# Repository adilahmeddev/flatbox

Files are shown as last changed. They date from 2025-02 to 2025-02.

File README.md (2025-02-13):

# Flatbox: Low profile hitbox-layout fightstick

This repository contains 3D-printable models, PCB design files and code needed to make an arcade controller that looks like this:

Assembled Flatbox

There are seven major versions of the Flatbox. They all use Kailh low profile (choc v1) mechanical keyboard switches. The table below lists their main features. See the README for each version for details on how to make them.

version | case dimensions (mm) | compatibility | add-on board | onboard chip | SMT assembly required | firmware
------- | --------------- | ------------- | ------------ | ------------ | --------------------- | --------
[rev1.1](hardware-rev1.1) | 218x128x10 | PC, PS3 | Arduino Pro Micro | - | no | [ATmega32U4](firmware-atmega32u4)
[rev2](hardware-rev2) | 218x130x10 | PC, PS3 | - | ATmega32U4 | yes | [ATmega32U4](firmware-atmega32u4)
[rev3](hardware-rev3) | 218x130x10 | PC, PS3, PS4 or PC, Switch, PS3, PS4, PS5\* | [Brook PS3/PS4](https://www.brookaccessory.com/detail/58690501/) or [P5 mini](https://www.brookaccessory.com/detail/92299183/) | - | yes | [Brook](https://www.brookaccessory.com/download/)
[rev4](hardware-rev4) | 218x130x10 | PC, PS3, PS4\*, Switch | - | RP2040 | yes | [GP2040-CE](https://gp2040-ce.info/)
[rev5](hardware-rev5) | 218x126x10 | PC, PS3, PS4\*, Switch | [RP2040-Zero](https://www.waveshare.com/rp2040-zero.htm) | - | no | [GP2040-CE](https://gp2040-ce.info/)
[rev6](hardware-rev6) | 218x126x10 | PC, Switch | - | CH552T | yes | [CH552](firmware-ch552)
[rev7](hardware-rev7) | 218x130x11 | PC | [Xiao nRF52840](https://www.seeedstudio.com/Seeed-XIAO-BLE-nRF52840-p-5201.html) | - | no | [slimbox-bt](https://github.com/jfedor2/slimbox-bt)

\* - with caveats

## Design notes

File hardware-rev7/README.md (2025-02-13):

# Flatbox rev7

This is rev7 of the Flatbox. In this version a [Seeed Studio XIAO nRF52840](https://www.seeedstudio.com/Seeed-XIAO-BLE-nRF52840-p-5201.html) board is soldered onto the main PCB.

To make one you will need:

* [3D printed case parts](3d-printed-case) - top and bottom
* [the Flatbox PCB](pcb)
* [Seeed Studio XIAO nRF52840](https://www.seeedstudio.com/Seeed-XIAO-BLE-nRF52840-p-5201.html)
* [MCP23017-E/SP](https://www.microchip.com/en-us/product/mcp23017) I2C I/O expander
* lipo battery - I used [this 1200mAh one from Pimoroni](https://shop.pimoroni.com/products/lipo-battery-pack?variant=20429082183)
* 12x Kailh low profile (choc v1) switches of your choice
* (optionally) 12x Kailh low profile hotswap sockets
* [3D printed buttoncaps](../3d-printed-buttoncaps)
* 6x 6x6x5mm tact switches
* 7x M3x6 flat head (countersunk) screws
* (optionally) 5x M2x4 screws to secure the PCB to the case
* some kind of rubber feet or non-slip padding for the bottom
* a soldering iron

I think this [lipo battery from Adafruit](https://www.adafruit.com/product/258) is the same thing as the Pimoroni one, though I'm not sure about the cable length.

Make sure you get the MCP23017 expander in DIP package. Observe pin 1 orientation when soldering.

I printed the case at 0.20mm layer height. The top part should be printed upside-down, the bottom part should be printed as-is. They don't require supports.

The PCB can be ordered from a number of online services using the included [Gerber files](pcb), I used [JLCPCB](https://jlcpcb.com/) (leave all the settings at default, you can choose the PCB color). PCB thickness should be 1.6mm.

Flatbox rev7 unpopulated PCB

The switches can be soldered in directly to the PCB or you can use hotswap sockets.

You will need to cut off the plug on the battery and solder the wires directly to pads on the bottom of the Xiao board.

Flatbox rev7 battery wiring

To flash the firmware, download the [flatbox-rev7.uf2](https://github.com/jfedor2/slimbox-bt/releases/latest/download/flatbox-rev7.uf2) file from the [slimbox-bt](https://github.com/jfedor2/slimbox-bt) repository. Then connect the board to your computer using a USB cable and press the RESET button on the Xiao board twice quickly (the RESET button is really small, next to the USB port). A USB drive should appear on your computer. Copy the `flatbox-rev7.uf2` file to that drive.

See the [slimbox-bt](https://github.com/jfedor2/slimbox-bt) repository for general usage instructions.

Flatbox rev7 inside the case

Flatbox rev7 exploded view of the case

PCB design licensed under [CC BY-SA 4.0](https://creativecommons.org/licenses/by-sa/4.0/).

PCB/case design uses the following:

* [keyswitches.pretty](https://github.com/daprice/keyswitches.pretty) by [daprice](https://github.com/daprice) ([CC BY-SA 4.0](https://creativecommons.org/licenses/by-sa/4.0/))
* Xiao STEP file downloaded from [GrabCAD](https://grabcad.com/library/seeed-studio-xiao-nrf52840-sense-1)

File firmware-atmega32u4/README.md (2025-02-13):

This is Arduino code for a USB arcade controller, meant to be used with ATmega32U4-based boards like the Arduino Pro Micro.

It works with Flatbox [rev1](../hardware-rev1), [rev1.1](../hardware-rev1.1) and [rev2](../hardware-rev2).

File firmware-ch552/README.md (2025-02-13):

This is gamepad firmware that runs on the CH552T chip. It works with Flatbox [rev6](../hardware-rev6).

It is a minor modification of Stefan Wagner's [CH552-MouseWiggler](https://github.com/wagiminator/CH552-MouseWiggler).

To compile the firmware you need the `sdcc` compiler. To flash the firmware you need the `pyusb` Python module.

To build the firmware, run `make bin`.

To build and flash the firmware onto a board, hold the "BOOT" button while plugging the board into your computer, then run `make flash` immediately after.

To flash an existing binary, hold the "BOOT" button while plugging the board into your computer, then run `python3 tools/chprog.py gamepad.bin` immediately after.

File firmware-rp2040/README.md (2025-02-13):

This is the firmware I originally wrote for the RP2040 versions of the Flatbox ([rev4](../hardware-rev4) and [rev5](../hardware-rev5)). It is very simple and easy to understand and modify. It works with PC and PS3.

Since then, [GP2040-CE](https://gp2040-ce.info/) emerged as the de facto standard firmware for RP2040-based boards. It has many nice features like remappable buttons and configurable SOCD cleaner. You probably just want to use that instead of the firmware here. Go to the [GP2040-CE downloads page](https://gp2040-ce.info/downloads/) and get the UF2 file matching your board (Flatbox rev4 or rev5, *not* the Waveshare RP2040-Zero one, even if your rev5 board uses it).

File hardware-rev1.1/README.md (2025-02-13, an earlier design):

# Flatbox rev1.1

This is rev1.1 of the Flatbox. In this version an Arduino Pro Micro is soldered onto the main PCB.

To make one you will need:

* [3D printed case parts](3d-printed-case) - top and bottom
* [the Flatbox PCB](pcb)
* Arduino Pro Micro
* 12x Kailh low profile (choc v1) switches of your choice
* (optionally) 12x Kailh low profile hotswap sockets
* [3D printed buttoncaps](../3d-printed-buttoncaps)
* 6x 6x6x5mm tact switches
* 7x 3x10mm wood screws
* some kind of rubber feet or non-slip padding for the bottom
* a soldering iron

I printed the case at 0.20mm layer height. The top part should be printed upside-down, the bottom part should be printed as-is. They don't require supports.

The PCB can be ordered from a number of online services using the included [Gerber files](pcb), I used [JLCPCB](https://jlcpcb.com/) (leave all the settings at default, you can choose the PCB color). PCB thickness should be 1.6mm.

The switches can be soldered in directly to the PCB or you can use hotswap sockets. If you want to use hotswap sockets, you will have to print the appropriate bottom part of the case (it's 1mm thicker).

The Arduino has to be soldered directly on top of the PCB, otherwise it won't fit in the case (the plastic base of the pin header can't go between the Arduino and the PCB).

You don't have to use the [code](../firmware-atmega32u4) included here, you can use any other ATmega32U4-compatible firmware. The included firmware works with the PS3 and PC.

Flatbox rev1.1 unpopulated PCB

Arduino Pro Micro soldered on top of the PCB

Flatbox rev1.1 exploded view of the 3D printed case

PCB design licensed under [CC BY-SA 4.0](https://creativecommons.org/licenses/by-sa/4.0/).

PCB design uses the following libraries:

* [keyswitches.pretty](https://github.com/daprice/keyswitches.pretty) by [daprice](https://github.com/daprice) ([CC BY-SA 4.0](https://creativecommons.org/licenses/by-sa/4.0/))
* [ProMicroKiCad](https://github.com/Biacco42/ProMicroKiCad) by [Biacco42](https://github.com/Biacco42), derived from [teensy\_library](https://github.com/XenGi/teensy_library) by Ricardo Band ([MIT License](https://opensource.org/licenses/mit-license.php))

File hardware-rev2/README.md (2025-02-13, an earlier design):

# Flatbox rev2

This is rev2 of the Flatbox. In this version the PCB includes a microcontroller and USB port. Everything is built in, you only have to add the switches (and flash the firmware).

To make one you will need:

* [3D printed case parts](3d-printed-case) - top and bottom
* [the PCB](pcb)
* 12x Kailh low profile (choc v1) switches of your choice
* (optionally) 12x Kailh low profile hotswap sockets
* [3D printed buttoncaps](../3d-printed-buttoncaps)
* 6x 6x6x5mm tact switches
* 7x 3x10mm wood screws
* some kind of rubber feet or non-slip padding for the bottom
* a soldering iron
* an ISP programmer or an Arduino to flash the board with [firmware](../firmware-atmega32u4)

I printed the case at 0.20mm layer height. The top part should be printed upside-down, the bottom part should be printed as-is. They don't require supports.

I used [JLCPCB](https://jlcpcb.com/) to make the PCB and assemble the SMD parts. The [included files](pcb) can be used with JLCPCB directly. If you want to use some other service, check the file formats that they expect. When ordering from JLCPCB, upload the Gerber zip, leave all the settings at default (you can choose the PCB color), then select "SMT Assembly" and upload the BOM and CPL files. PCB thickness should be 1.6mm.

The PCB you get from JLCPCB will look like this:

Flatbox rev2 PCB with SMD parts assembled

The switches can be soldered in directly to the PCB or you can use hotswap sockets. If you want to use hotswap sockets, you will have to print the appropriate bottom part of the case (it's 1mm thicker).

You don't have to use the [code](../firmware-atmega32u4) included here, you can use any other ATmega32U4-compatible firmware. The included firmware works with the PS3 and PC.

To flash the firmware, we first flash the board with an Arduino Pro Micro bootloader, effectively making it look like an Arduino from the computer's point of view. To do that you're going to need an ISP programmer, either a dedicated one or you can [use an Arduino as an ISP programmer](https://www.arduino.cc/en/Tutorial/BuiltInExamples/ArduinoISP). Install the [SparkFun Arduino add-on](https://learn.sparkfun.com/tutorials/pro-micro--fio-v3-hookup-guide#windows_boardaddon), connect the VCC, MISO, MOSI, SCK, RESET and GND wires, select Arduino Pro Micro 16MHz/5V as the board, select the right programmer depending on the option you went for, and then select "Burn bootloader". If this succeeds, your Flatbox is now an Arduino Pro Micro and you can flash the actual firmware like you would any other Arduino sketch on an actual Arduino board.

(This is not the only way to flash the firmware. The ATmega32U4 chip comes pre-programmed with a DFU bootloader, so in theory you could use that to flash the Arduino bootloader or just flash the firmware directly. But I think the option described above is easier, even though it requires an ISP programmer, because you just use the Arduino IDE for everything.)

Flatbox rev2 exploded view of the 3D printed case

PCB design licensed under [CC BY-SA 4.0](https://creativecommons.org/licenses/by-sa/4.0/).

PCB design uses the following libraries:

* [keyswitches.pretty](https://github.com/daprice/keyswitches.pretty) by [daprice](https://github.com/daprice) ([CC BY-SA 4.0](https://creativecommons.org/licenses/by-sa/4.0/))
* [Type-C.pretty](https://github.com/ai03-2725/Type-C.pretty) by [ai03-2725](https://github.com/ai03-2725)

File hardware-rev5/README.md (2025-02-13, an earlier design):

# Flatbox rev5

This is rev5 of the Flatbox. In this version an [RP2040-Zero](https://www.waveshare.com/rp2040-zero.htm) board is soldered onto the main PCB.

To make one you will need:

* [3D printed](3d-printed-case) or [CNC machined](cnc-machined-case) case parts - top and bottom
* [the Flatbox PCB](pcb)
* [RP2040-Zero](https://www.waveshare.com/rp2040-zero.htm)
* 12x Kailh low profile (choc v1) switches of your choice
* (optionally) 12x Kailh low profile hotswap sockets
* [3D printed buttoncaps](../3d-printed-buttoncaps)
* 6x tact switches: 6x6x5mm for the 3D printed case and 6x6x7mm or 6x6x8mm for the CNC machined case
* 7x M3x6 flat head screws
* some kind of rubber feet or non-slip padding for the bottom
* a soldering iron

I printed the case at 0.20mm layer height. The top part should be printed upside-down, the bottom part should be printed as-is. They don't require supports.

The CNC machined case can be ordered at [JLCPCB](https://jlcpcb.com/). I used 6061 aluminum. There are various surface finish options like bead blasting and anodizing that you can select. Be sure to select the "threads" option for the top part and upload the PDF file.

The PCB can be ordered from a number of online services using the included [Gerber files](pcb), I used [JLCPCB](https://jlcpcb.com/) (leave all the settings at default, you can choose the PCB color). PCB thickness should be 1.6mm.

The switches can be soldered in directly to the PCB or you can use hotswap sockets. If you want to use hotswap sockets, you will have to print the appropriate bottom part of the case (it's 1mm thicker). The CNC machined case is also hotswap compatible.

For the firmware you probably want to use [GP2040-CE](https://gp2040-ce.info/). Go to the [GP2040-CE downloads page](https://gp2040-ce.info/downloads/) and get the UF2 file for Flatbox rev5. Do not get the file for the Waveshare RP2040-Zero, even though your stick uses it (it has a different pinout).

To flash the firmware, connect the board to a computer with a USB cable, then press the RESET button while holding the BOOT button on the RP2040-Zero. A drive named "RPI-RP2" should appear. Copy the UF2 file you downloaded to that drive. That's it.

(Of course you can also use any other RP2040-compatible firmware if you want.)

Flatbox rev5 unpopulated PCB

RP2040-Zero soldered on top of the PCB

Flatbox rev5 exploded view of the 3D printed case

PCB design licensed under [CC BY-SA 4.0](https://creativecommons.org/licenses/by-sa/4.0/).

PCB design uses the following:

* [keyswitches.pretty](https://github.com/daprice/keyswitches.pretty) by [daprice](https://github.com/daprice) ([CC BY-SA 4.0](https://creativecommons.org/licenses/by-sa/4.0/))
* RP2040-Zero STEP file downloaded from [Waveshare wiki](https://www.waveshare.com/wiki/RP2040-Zero)

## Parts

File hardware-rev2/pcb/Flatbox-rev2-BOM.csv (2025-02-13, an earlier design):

Comment | Designator | Footprint | LCSC
22p | C1,C2 | Capacitor_SMD:C_0603_1608Metric | C1653
1u | C3 | Capacitor_SMD:C_0603_1608Metric | C15849
0.1u | C4,C5,C6 | Capacitor_SMD:C_0402_1005Metric | C1525
10u | C7 | Capacitor_SMD:C_0603_1608Metric | C19702
500m | F1 | Fuse:Fuse_1206_3216Metric | C70069
10k | R1,R2 | Resistor_SMD:R_0805_2012Metric | C17414
22 | R3,R4 | Resistor_SMD:R_0805_2012Metric | C17561
5.1k | R5,R6 | Resistor_SMD:R_0805_2012Metric | C27834
ATmega32U4-AU | U1 | Package_QFP:TQFP-44_10x10mm_P0.8mm | C44854
HRO-TYPE-C-31-M-12 | USB1 | Type-C:HRO-TYPE-C-31-M-12-Assembly | C165948
XTAL | Y1 | Crystal:Crystal_SMD_3225-4Pin_3.2x2.5mm | C179641

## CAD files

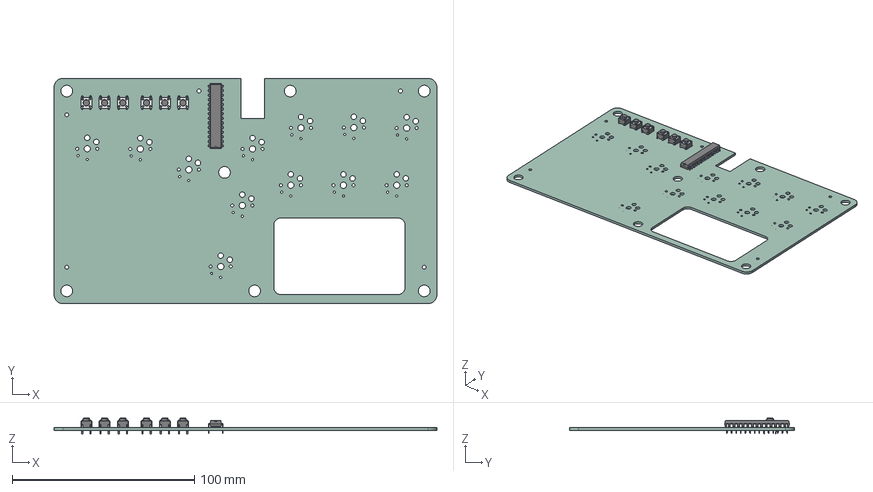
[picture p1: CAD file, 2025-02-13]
hardware-rev7/extras/Flatbox-rev7-pcb.step
210.0 x 123.6 x 8.50 mm
SW_PUSH_6mm_h5mm x 6
DIP-28_W7.62mm
Flatbox-rev7_PCB

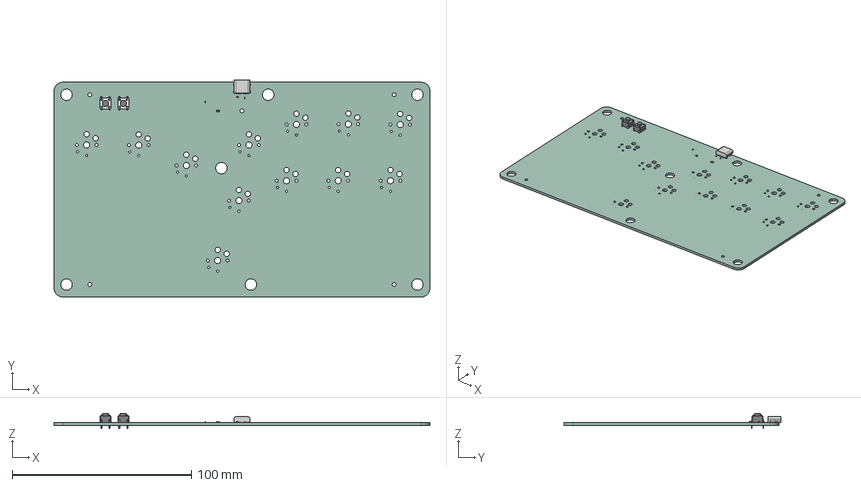
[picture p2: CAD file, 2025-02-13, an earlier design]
hardware-rev6/extras/Flatbox-rev6-pcb.step
210.0 x 121.2 x 8.50 mm
SW_PUSH_6mm_h5mm x 2
R_0402_1005Metric x 3
HRO TYPE-C-31-M-12 v4
C_0402_1005Metric x 2
Flatbox-rev6_PCB

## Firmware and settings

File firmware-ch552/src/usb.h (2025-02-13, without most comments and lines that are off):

#pragma once
#include <stdint.h>
#define USB_PID_NULL            0x00  // reserved PID
#define USB_PID_SOF             0x05
#define USB_PID_SETUP           0x0D
#define USB_PID_IN              0x09
#define USB_PID_OUT             0x01
#define USB_PID_ACK             0x02
#define USB_PID_NAK             0x0A
#define USB_PID_STALL           0x0E
#define USB_PID_DATA0           0x03
#define USB_PID_DATA1           0x0B
#define USB_PID_PRE             0x0C
#define USB_GET_STATUS          0x00
#define USB_CLEAR_FEATURE       0x01
#define USB_SET_FEATURE         0x03
#define USB_SET_ADDRESS         0x05
#define USB_GET_DESCRIPTOR      0x06
#define USB_SET_DESCRIPTOR      0x07
#define USB_GET_CONFIGURATION   0x08
#define USB_SET_CONFIGURATION   0x09
#define USB_GET_INTERFACE       0x0A
#define USB_SET_INTERFACE       0x0B
#define USB_SYNCH_FRAME         0x0C
#define HUB_GET_STATUS          0x00
#define HUB_CLEAR_FEATURE       0x01
#define HUB_GET_STATE           0x02
#define HUB_SET_FEATURE         0x03
#define HUB_GET_DESCRIPTOR      0x06
#define HUB_SET_DESCRIPTOR      0x07
#define HID_GET_REPORT          0x01
#define HID_GET_IDLE            0x02
#define HID_GET_PROTOCOL        0x03
#define HID_SET_REPORT          0x09
#define HID_SET_IDLE            0x0A
#define HID_SET_PROTOCOL        0x0B
#define USB_REQ_TYP_IN          0x80  // control IN, device to host
#define USB_REQ_TYP_OUT         0x00  // control OUT, host to device
#define USB_REQ_TYP_READ        0x80  // control read, device to host
#define USB_REQ_TYP_WRITE       0x00  // control write, host to device
#define USB_REQ_TYP_MASK        0x60  // bit mask of request type
#define USB_REQ_TYP_STANDARD    0x00
#define USB_REQ_TYP_CLASS       0x20
#define USB_REQ_TYP_VENDOR      0x40
#define USB_REQ_TYP_RESERVED    0x60
#define USB_REQ_RECIP_MASK      0x1F  // bit mask of request recipient
#define USB_REQ_RECIP_DEVICE    0x00
#define USB_REQ_RECIP_INTERF    0x01
#define USB_REQ_RECIP_ENDP      0x02
#define USB_REQ_RECIP_OTHER     0x03
#define HUB_CLEAR_HUB_FEATURE   0x20
#define HUB_CLEAR_PORT_FEATURE  0x23
#define HUB_GET_BUS_STATE       0xA3
#define HUB_GET_HUB_DESCRIPTOR  0xA0
#define HUB_GET_HUB_STATUS      0xA0
#define HUB_GET_PORT_STATUS     0xA3
#define HUB_SET_HUB_DESCRIPTOR  0x20
#define HUB_SET_HUB_FEATURE     0x20
#define HUB_SET_PORT_FEATURE    0x23
#define HUB_C_HUB_LOCAL_POWER   0
#define HUB_C_HUB_OVER_CURRENT  1
#define HUB_PORT_CONNECTION     0
#define HUB_PORT_ENABLE         1
#define HUB_PORT_SUSPEND        2
#define HUB_PORT_OVER_CURRENT   3
#define HUB_PORT_RESET          4
#define HUB_PORT_POWER          8
#define HUB_PORT_LOW_SPEED      9
#define HUB_C_PORT_CONNECTION   16
#define HUB_C_PORT_ENABLE       17
#define HUB_C_PORT_SUSPEND      18
#define HUB_C_PORT_OVER_CURRENT 19
#define HUB_C_PORT_RESET        20
#define USB_DESCR_TYP_DEVICE    0x01
#define USB_DESCR_TYP_CONFIG    0x02
#define USB_DESCR_TYP_STRING    0x03
#define USB_DESCR_TYP_INTERF    0x04
#define USB_DESCR_TYP_ENDP      0x05
#define USB_DESCR_TYP_QUALIF    0x06
#define USB_DESCR_TYP_SPEED     0x07
#define USB_DESCR_TYP_OTG       0x09
#define USB_DESCR_TYP_IAD       0x0B
#define USB_DESCR_TYP_HID       0x21
#define USB_DESCR_TYP_REPORT    0x22
#define USB_DESCR_TYP_PHYSIC    0x23
#define USB_DESCR_TYP_CS_INTF   0x24
#define USB_DESCR_TYP_CS_ENDP   0x25
#define USB_DESCR_TYP_HUB       0x29
#define USB_DEV_CLASS_RESERVED  0x00
#define USB_DEV_CLASS_AUDIO     0x01
#define USB_DEV_CLASS_COMM      0x02
#define USB_DEV_CLASS_HID       0x03
#define USB_DEV_CLASS_MONITOR   0x04
#define USB_DEV_CLASS_PHYSIC_IF 0x05
#define USB_DEV_CLASS_POWER     0x06
#define USB_DEV_CLASS_PRINTER   0x07
#define USB_DEV_CLASS_STORAGE   0x08
#define USB_DEV_CLASS_HUB       0x09
#define USB_DEV_CLASS_DATA      0x0A
#define USB_DEV_CLASS_MISC      0xEF
#define USB_DEV_CLASS_VENDOR    0xFF
#define USB_ENDP_DIR_MASK       0x80
#define USB_ENDP_ADDR_MASK      0x0F
#define USB_ENDP_TYPE_MASK      0x03
#define USB_ENDP_TYPE_CTRL      0x00
#define USB_ENDP_TYPE_ISOCH     0x01
#define USB_ENDP_TYPE_BULK      0x02
#define USB_ENDP_TYPE_INTER     0x03
#define USB_ENDP_ADDR_EP1_OUT   0x01
#define USB_ENDP_ADDR_EP1_IN    0x81
#define USB_ENDP_ADDR_EP2_OUT   0x02
#define USB_ENDP_ADDR_EP2_IN    0x82
#define USB_ENDP_ADDR_EP3_OUT   0x03
#define USB_ENDP_ADDR_EP3_IN    0x83
#define USB_ENDP_ADDR_EP4_OUT   0x04
#define USB_ENDP_ADDR_EP4_IN    0x84
  #define USB_DEVICE_ADDR       0x02  // default USB device address
  #define DEFAULT_ENDP0_SIZE    8     // default maximum packet size for endpoint 0
  #define DEFAULT_ENDP1_SIZE    8     // default maximum packet size for endpoint 1
  #define MAX_PACKET_SIZE       64    // maximum packet size
  #define USB_BO_CBW_SIZE       0x1F  // total length of command block CBW
  #define USB_BO_CSW_SIZE       0x0D  // total length of command status block CSW
  #define USB_BO_CBW_SIG0       0x55  // command block CBW identification flag 'USBC'
  #define USB_BO_CBW_SIG1       0x53
  #define USB_BO_CBW_SIG2       0x42
  #define USB_BO_CBW_SIG3       0x43
  #define USB_BO_CSW_SIG0       0x55  // command status block CSW identification flag 'USBS'
  #define USB_BO_CSW_SIG1       0x53
  #define USB_BO_CSW_SIG2       0x42
  #define USB_BO_CSW_SIG3       0x53
typedef struct _USB_SETUP_REQ {
    uint8_t  bRequestType;
    uint8_t  bRequest;
    uint8_t  wValueL;
    uint8_t  wValueH;
    uint8_t  wIndexL;
    uint8_t  wIndexH;
    uint8_t  wLengthL;
    uint8_t  wLengthH;
} USB_SETUP_REQ, *PUSB_SETUP_REQ;
typedef USB_SETUP_REQ __xdata *PXUSB_SETUP_REQ;
typedef struct _USB_DEVICE_DESCR {
    uint8_t  bLength;
    uint8_t  bDescriptorType;
    uint16_t bcdUSB;
    uint8_t  bDeviceClass;
    uint8_t  bDeviceSubClass;
    uint8_t  bDeviceProtocol;
    uint8_t  bMaxPacketSize0;
    uint16_t idVendor;
    uint16_t idProduct;
    uint16_t bcdDevice;
    uint8_t  iManufacturer;
    uint8_t  iProduct;
    uint8_t  iSerialNumber;
    uint8_t  bNumConfigurations;
} USB_DEV_DESCR, *PUSB_DEV_DESCR;
typedef USB_DEV_DESCR __xdata *PXUSB_DEV_DESCR;
typedef struct _USB_CONFIG_DESCR {
    uint8_t  bLength;
    uint8_t  bDescriptorType;
    uint16_t wTotalLength;
    uint8_t  bNumInterfaces;
    uint8_t  bConfigurationValue;
    uint8_t  iConfiguration;
    uint8_t  bmAttributes;
    uint8_t  MaxPower;
} USB_CFG_DESCR, *PUSB_CFG_DESCR;
typedef USB_CFG_DESCR __xdata *PXUSB_CFG_DESCR;
typedef struct _USB_INTERF_DESCR {
    uint8_t  bLength;
    uint8_t  bDescriptorType;
    uint8_t  bInterfaceNumber;
    uint8_t  bAlternateSetting;
    uint8_t  bNumEndpoints;
    uint8_t  bInterfaceClass;
    uint8_t  bInterfaceSubClass;
    uint8_t  bInterfaceProtocol;
    uint8_t  iInterface;
} USB_ITF_DESCR, *PUSB_ITF_DESCR;
typedef USB_ITF_DESCR __xdata *PXUSB_ITF_DESCR;
typedef struct _USB_ITF_ASS_DESCR {
    uint8_t  bLength;
    uint8_t  bDescriptorType;
    uint8_t  bFirstInterface;
    uint8_t  bInterfaceCount;
    uint8_t  bFunctionClass;
    uint8_t  bFunctionSubClass;
    uint8_t  bFunctionProtocol;
    uint8_t  iFunction;
} USB_IAD_DESCR, *PUSB_IAD_DESCR;
typedef USB_IAD_DESCR __xdata *PXUSB_IAD_DESCR;
typedef struct _USB_ENDPOINT_DESCR {
    uint8_t  bLength;
    uint8_t  bDescriptorType;
    uint8_t  bEndpointAddress;
    uint8_t  bmAttributes;
    uint16_t wMaxPacketSize;
    uint8_t  bInterval;
} USB_ENDP_DESCR, *PUSB_ENDP_DESCR;
typedef USB_ENDP_DESCR __xdata *PXUSB_ENDP_DESCR;
typedef struct _USB_CONFIG_DESCR_LONG {
    USB_CFG_DESCR   cfg_descr;
    USB_ITF_DESCR   itf_descr;
    USB_ENDP_DESCR  endp_descr[1];
} USB_CFG_DESCR_LONG, *PUSB_CFG_DESCR_LONG;
typedef USB_CFG_DESCR_LONG __xdata *PXUSB_CFG_DESCR_LONG;
typedef struct _USB_HUB_DESCR {
    uint8_t  bDescLength;
    uint8_t  bDescriptorType;
    uint8_t  bNbrPorts;
    uint16_t wHubCharacteristics;
    uint8_t  bPwrOn2PwrGood;
    uint8_t  bHubContrCurrent;
    uint8_t  DeviceRemovable;
    uint8_t  PortPwrCtrlMask;
} USB_HUB_DESCR, *PUSB_HUB_DESCR;
typedef USB_HUB_DESCR __xdata *PXUSB_HUB_DESCR;
typedef struct _USB_HID_DESCR {
    uint8_t  bLength;
    uint8_t  bDescriptorType;
    uint16_t bcdHID;
    uint8_t  bCountryCode;
    uint8_t  bNumDescriptors;
    uint8_t  bDescriptorTypeX;
    uint16_t wDescriptorLength;
} USB_HID_DESCR, *PUSB_HID_DESCR;
typedef USB_HID_DESCR __xdata *PXUSB_HID_DESCR;
typedef struct _UDISK_BOC_CBW {             // command of BulkOnly USB-FlashDisk
    uint8_t mCBW_Sig0;
    uint8_t mCBW_Sig1;
    uint8_t mCBW_Sig2;
    uint8_t mCBW_Sig3;
    uint8_t mCBW_Tag0;
    uint8_t mCBW_Tag1;
    uint8_t mCBW_Tag2;
    uint8_t mCBW_Tag3;
    uint8_t mCBW_DataLen0;
    uint8_t mCBW_DataLen1;
    uint8_t mCBW_DataLen2;
    uint8_t mCBW_DataLen3;                  // uppest byte of data length, always is 0
    uint8_t mCBW_Flag;                      // transfer direction and etc.
    uint8_t mCBW_LUN;
    uint8_t mCBW_CB_Len;                    // length of command block
    uint8_t mCBW_CB_Buf[16];                // command block buffer
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

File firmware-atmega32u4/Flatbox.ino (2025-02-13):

// Jacek Fedorynski <jfedor@jfedor.org>
// http://www.jfedor.org/

// Uncomment the appropriate line to match your stick version
#define REV1
//#define REV2

#include "HID.h"

#ifdef REV1

#define PIN_UP        9
#define PIN_DOWN      7
#define PIN_LEFT      6
#define PIN_RIGHT     8
#define PIN_CROSS     10
#define PIN_CIRCLE    14
#define PIN_TRIANGLE  15
#define PIN_SQUARE    16
#define PIN_L1        21
#define PIN_L2        20
#define PIN_R1        19
#define PIN_R2        18
#define PIN_SELECT    2
#define PIN_START     1
#define PIN_L3        5
#define PIN_R3        3
#define PIN_PS        0

#endif

#ifdef REV2

#define PIN_UP        5
#define PIN_DOWN      9
#define PIN_LEFT      8
#define PIN_RIGHT     10
#define PIN_CROSS     18
#define PIN_CIRCLE    21
#define PIN_TRIANGLE  14
#define PIN_SQUARE    7
#define PIN_L1        15
#define PIN_L2        19
#define PIN_R1        16
#define PIN_R2        20
#define PIN_SELECT    1
#define PIN_START     4
#define PIN_L3        3
#define PIN_R3        0
#define PIN_PS        6

#endif

int stickMode = 0; // 0 = dpad, 1 = left stick

// HID report descriptor taken from a HORI Fighting Stick V3
// works out of the box with PC and PS3
// as dumped by usbhid-dump and parsed by https://eleccelerator.com/usbdescreqparser/
static const uint8_t hidReportDescriptor[] PROGMEM = {
  0x05, 0x01,        // Usage Page (Generic Desktop Ctrls)
  0x09, 0x05,        // Usage (Game Pad)
  0xA1, 0x01,        // Collection (Application)
  0x85, 0x01,        // Report ID, not in the original descriptor, but the Arduino HID library can't seem to live without it
  0x15, 0x00,        //   Logical Minimum (0)
  0x25, 0x01,        //   Logical Maximum (1)
  0x35, 0x00,        //   Physical Minimum (0)
  0x45, 0x01,        //   Physical Maximum (1)
  0x75, 0x01,        //   Report Size (1)
  0x95, 0x0D,        //   Report Count (13)
  0x05, 0x09,        //   Usage Page (Button)
  0x19, 0x01,        //   Usage Minimum (0x01)
  0x29, 0x0D,        //   Usage Maximum (0x0D)
  0x81, 0x02,        //   Input (Data,Var,Abs,No Wrap,Linear,Preferred State,No Null Position)
  0x95, 0x03,        //   Report Count (3)
  0x81, 0x01,        //   Input (Const,Array,Abs,No Wrap,Linear,Preferred State,No Null Position)
  0x05, 0x01,        //   Usage Page (Generic Desktop Ctrls)
  0x25, 0x07,        //   Logical Maximum (7)
  0x46, 0x3B, 0x01,  //   Physical Maximum (315)
  0x75, 0x04,        //   Report Size (4)
  0x95, 0x01,        //   Report Count (1)
  0x65, 0x14,        //   Unit (System: English Rotation, Length: Centimeter)
  0x09, 0x39,        //   Usage (Hat switch)
  0x81, 0x42,        //   Input (Data,Var,Abs,No Wrap,Linear,Preferred State,Null State)
  0x65, 0x00,        //   Unit (None)
  0x95, 0x01,        //   Report Count (1)
  0x81, 0x01,        //   Input (Const,Array,Abs,No Wrap,Linear,Preferred State,No Null Position)
  0x26, 0xFF, 0x00,  //   Logical Maximum (255)
  0x46, 0xFF, 0x00,  //   Physical Maximum (255)
  0x09, 0x30,        //   Usage (X)
  0x09, 0x31,        //   Usage (Y)
  0x09, 0x32,        //   Usage (Z)
  0x09, 0x35,        //   Usage (Rz)
  0x75, 0x08,        //   Report Size (8)
  0x95, 0x04,        //   Report Count (4)
  0x81, 0x02,        //   Input (Data,Var,Abs,No Wrap,Linear,Preferred State,No Null Position)
  0x06, 0x00, 0xFF,  //   Usage Page (Vendor Defined 0xFF00)
  0x09, 0x20,        //   Usage (0x20)
  0x09, 0x21,        //   Usage (0x21)
  0x09, 0x22,        //   Usage (0x22)
  0x09, 0x23,        //   Usage (0x23)
  0x09, 0x24,        //   Usage (0x24)
  0x09, 0x25,        //   Usage (0x25)
  0x09, 0x26,        //   Usage (0x26)
  0x09, 0x27,        //   Usage (0x27)
  0x09, 0x28,        //   Usage (0x28)
  0x09, 0x29,        //   Usage (0x29)
  0x09, 0x2A,        //   Usage (0x2A)
  0x09, 0x2B,        //   Usage (0x2B)
  0x95, 0x0C,        //   Report Count (12)
  0x81, 0x02,        //   Input (Data,Var,Abs,No Wrap,Linear,Preferred State,No Null Position)
  0x0A, 0x21, 0x26,  //   Usage (0x2621)
  0x95, 0x08,        //   Report Count (8)
  0xB1, 0x02,        //   Feature (Data,Var,Abs,No Wrap,Linear,Preferred State,No Null Position,Non-volatile)
  0x0A, 0x21, 0x26,  //   Usage (0x2621)
  0x91, 0x02,        //   Output (Data,Var,Abs,No Wrap,Linear,Preferred State,No Null Position,Non-volatile)
  0x26, 0xFF, 0x03,  //   Logical Maximum (1023)
  0x46, 0xFF, 0x03,  //   Physical Maximum (1023)
  0x09, 0x2C,        //   Usage (0x2C)
  0x09, 0x2D,        //   Usage (0x2D)
  0x09, 0x2E,        //   Usage (0x2E)
  0x09, 0x2F,        //   Usage (0x2F)
  0x75, 0x10,        //   Report Size (16)
  0x95, 0x04,        //   Report Count (4)
  0x81, 0x02,        //   Input (Data,Var,Abs,No Wrap,Linear,Preferred State,No Null Position)
  0xC0,              // End Collection
};

typedef struct {
  uint16_t buttons; // bits: 0 = square, 1 = cross, 2 = circle, 3 = triangle,
                    // 4 = L1, 5 = R1, 6 = L2, 7 = R2, 8 = select, 9 = start,
                    // 10 = L3, 11 = R3, 12 = PS
  uint8_t dpadHat; // 0 = up, 1 = up/right, 2 = right etc., 0x0f = neutral
  uint8_t leftStickXAxis;
  uint8_t leftStickYAxis;
  uint8_t rightStickXAxis;
  uint8_t rightStickYAxis;
  uint8_t dpadRightAxis;
  uint8_t dpadLeftAxis;
  uint8_t dpadUpAxis;
  uint8_t dpadDownAxis;
  uint8_t triangleAxis;
  uint8_t circleAxis;
  uint8_t crossAxis;
  uint8_t squareAxis;
  uint8_t L1Axis;
  uint8_t L2Axis;
  uint8_t R1Axis;
  uint8_t R2Axis;
  uint16_t accelerometerXAxis; // 10 bits (these are guesses BTW)
  uint16_t accelerometerYAxis; // 10 bits
  uint16_t accelerometerZAxis; // 10 bits
  uint16_t gyroscopeAxis; // 10 bits
} hid_report_t;

hid_report_t report;
hid_report_t prevReport;

void dpad(bool up, bool down, bool left, bool right) {
  if (up && down) {
    up = down = false;
  }
  if (left && right) {
    left = right = false;
  }

  switch (stickMode) {
    case 0:
      if (up && !right && !left) report.dpadHat = 0;
      else if (up && right) report.dpadHat = 1;
      else if (right && !up && !down) report.dpadHat = 2;
      else if (right && down) report.dpadHat = 3;
      else if (down && !right && !left) report.dpadHat = 4;
      else if (down && left) report.dpadHat = 5;
      else if (left && !down && !up) report.dpadHat = 6;
      else if (left && up) report.dpadHat = 7;
      else report.dpadHat = 0x0f;

      report.dpadRightAxis = right ? 0xff : 0x00;
      report.dpadLeftAxis = left ? 0xff : 0x00;
      report.dpadUpAxis = up ? 0xff : 0x00;
      report.dpadDownAxis = down ? 0xff : 0x00;
      break;
    case 1:
      report.leftStickXAxis = left ? 0x00 : (right ? 0xFF : 0x80);
      report.leftStickYAxis = up ? 0x00 : (down ? 0xFF : 0x80);
      break;
  }
}

void sendReport() {
  if (memcmp(&prevReport, &report, sizeof(report))) {
    HID().SendReport(1, &report, sizeof(report));
    memcpy(&prevReport, &report, sizeof(report));
  }
}

void setup() {
  static HIDSubDescriptor node(hidReportDescriptor, sizeof(hidReportDescriptor));
  HID().AppendDescriptor(&node);

  pinMode(PIN_UP, INPUT_PULLUP);
  pinMode(PIN_DOWN, INPUT_PULLUP);
  pinMode(PIN_LEFT, INPUT_PULLUP);
  pinMode(PIN_RIGHT, INPUT_PULLUP);
  pinMode(PIN_CROSS, INPUT_PULLUP);
  pinMode(PIN_CIRCLE, INPUT_PULLUP);
  pinMode(PIN_TRIANGLE, INPUT_PULLUP);
  pinMode(PIN_SQUARE, INPUT_PULLUP);
  pinMode(PIN_L1, INPUT_PULLUP);
  pinMode(PIN_L2, INPUT_PULLUP);
  pinMode(PIN_R1, INPUT_PULLUP);
  pinMode(PIN_R2, INPUT_PULLUP);
  pinMode(PIN_SELECT, INPUT_PULLUP);
  pinMode(PIN_START, INPUT_PULLUP);
  pinMode(PIN_L3, INPUT_PULLUP);
  pinMode(PIN_R3, INPUT_PULLUP);
  pinMode(PIN_PS, INPUT_PULLUP);

  // if left is held when plugged in, switch to left stick emulation mode
  if (digitalRead(PIN_LEFT) == LOW) {
    stickMode = 1;
  }

  memset(&report, 0, sizeof(report));
  report.dpadHat = 0x0f;
  report.accelerometerXAxis = 0x02; // not sure why 0x02, but that's what HORI Fighting Stick V3 sends
  report.accelerometerYAxis = 0x02;
  report.accelerometerZAxis = 0x02;
  report.gyroscopeAxis = 0x02;
  report.leftStickXAxis = 0x80;
  report.leftStickYAxis = 0x80;
  report.rightStickXAxis = 0x80;
  report.rightStickYAxis = 0x80;
  memcpy(&prevReport, &report, sizeof(report));
}

void loop() {
  report.buttons = 0x00;
  report.triangleAxis = 0x00;
  report.circleAxis = 0x00;
  report.crossAxis = 0x00;
  report.squareAxis = 0x00;
  report.L1Axis = 0x00;
  report.L2Axis = 0x00;
  report.R1Axis = 0x00;
  report.R2Axis = 0x00;

  dpad(digitalRead(PIN_UP) == LOW,
       digitalRead(PIN_DOWN) == LOW,
       digitalRead(PIN_LEFT) == LOW,
       digitalRead(PIN_RIGHT) == LOW);

  if (digitalRead(PIN_SQUARE) == LOW) {
    report.buttons |= 1 << 0;
    report.squareAxis = 0xff;
  }
  if (digitalRead(PIN_CROSS) == LOW) {
    report.buttons |= 1 << 1;
    report.crossAxis = 0xff;
  }
  if (digitalRead(PIN_CIRCLE) == LOW) {
    report.buttons |= 1 << 2;
    report.circleAxis = 0xff;
  }
  if (digitalRead(PIN_TRIANGLE) == LOW) {
    report.buttons |= 1 << 3;
    report.triangleAxis = 0xff;
  }
  if (digitalRead(PIN_L1) == LOW) {
    report.buttons |= 1 << 4;
    report.L1Axis = 0xff;
  }
  if (digitalRead(PIN_R1) == LOW) {
    report.buttons |= 1 << 5;
    report.R1Axis = 0xff;
  }
  if (digitalRead(PIN_L2) == LOW) {
    report.buttons |= 1 << 6;
    report.L2Axis = 0xff;
  }
  if (digitalRead(PIN_R2) == LOW) {
    report.buttons |= 1 << 7;
    report.R2Axis = 0xff;
  }
  if (digitalRead(PIN_SELECT) == LOW) {
    report.buttons |= 1 << 8;
  }
  if (digitalRead(PIN_START) == LOW) {
    report.buttons |= 1 << 9;
  }
  if (digitalRead(PIN_L3) == LOW) {
    report.buttons |= 1 << 10;
  }
  if (digitalRead(PIN_R3) == LOW) {
    report.buttons |= 1 << 11;
  }
  if (digitalRead(PIN_PS) == LOW) {
    report.buttons |= 1 << 12;
  }

  sendReport();
}

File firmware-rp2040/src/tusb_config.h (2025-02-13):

/*
 * The MIT License (MIT)
 *
 * Copyright (c) 2019 Ha Thach (tinyusb.org)
 *
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
 */

#ifndef _TUSB_CONFIG_H_
#define _TUSB_CONFIG_H_

#ifdef __cplusplus
 extern "C" {
#endif

//--------------------------------------------------------------------
// COMMON CONFIGURATION
//--------------------------------------------------------------------

// defined by board.mk
#ifndef CFG_TUSB_MCU
  #error CFG_TUSB_MCU must be defined
#endif

// RHPort number used for device can be defined by board.mk, default to port 0
#ifndef BOARD_DEVICE_RHPORT_NUM
  #define BOARD_DEVICE_RHPORT_NUM     0
#endif

// RHPort max operational speed can defined by board.mk
// Default to Highspeed for MCU with internal HighSpeed PHY (can be port specific), otherwise FullSpeed
#ifndef BOARD_DEVICE_RHPORT_SPEED
  #if (CFG_TUSB_MCU == OPT_MCU_LPC18XX || CFG_TUSB_MCU == OPT_MCU_LPC43XX || CFG_TUSB_MCU == OPT_MCU_MIMXRT10XX || \
       CFG_TUSB_MCU == OPT_MCU_NUC505  || CFG_TUSB_MCU == OPT_MCU_CXD56)
    #define BOARD_DEVICE_RHPORT_SPEED   OPT_MODE_HIGH_SPEED
  #else
    #define BOARD_DEVICE_RHPORT_SPEED   OPT_MODE_FULL_SPEED
  #endif
#endif

// Device mode with rhport and speed defined by board.mk
#if   BOARD_DEVICE_RHPORT_NUM == 0
  #define CFG_TUSB_RHPORT0_MODE     (OPT_MODE_DEVICE | BOARD_DEVICE_RHPORT_SPEED)
#elif BOARD_DEVICE_RHPORT_NUM == 1
  #define CFG_TUSB_RHPORT1_MODE     (OPT_MODE_DEVICE | BOARD_DEVICE_RHPORT_SPEED)
#else
  #error "Incorrect RHPort configuration"
#endif

#ifndef CFG_TUSB_OS
#define CFG_TUSB_OS               OPT_OS_NONE
#endif

// CFG_TUSB_DEBUG is defined by compiler in DEBUG build
// #define CFG_TUSB_DEBUG           0

/* USB DMA on some MCUs can only access a specific SRAM region with restriction on alignment.
 * Tinyusb use follows macros to declare transferring memory so that they can be put
 * into those specific section.
 * e.g
 * - CFG_TUSB_MEM SECTION : __attribute__ (( section(".usb_ram") ))
 * - CFG_TUSB_MEM_ALIGN   : __attribute__ ((aligned(4)))
 */
#ifndef CFG_TUSB_MEM_SECTION
#define CFG_TUSB_MEM_SECTION
#endif

#ifndef CFG_TUSB_MEM_ALIGN
#define CFG_TUSB_MEM_ALIGN          __attribute__ ((aligned(4)))
#endif

//--------------------------------------------------------------------
// DEVICE CONFIGURATION
//--------------------------------------------------------------------

#ifndef CFG_TUD_ENDPOINT0_SIZE
#define CFG_TUD_ENDPOINT0_SIZE    64
#endif

//------------- CLASS -------------//
#define CFG_TUD_HID               1
#define CFG_TUD_CDC               0
#define CFG_TUD_MSC               0
#define CFG_TUD_MIDI              0
#define CFG_TUD_VENDOR            0

// HID buffer size Should be sufficient to hold ID (if any) + Data
#define CFG_TUD_HID_EP_BUFSIZE    64

#ifdef __cplusplus
 }
#endif

#endif /* _TUSB_CONFIG_H_ */
